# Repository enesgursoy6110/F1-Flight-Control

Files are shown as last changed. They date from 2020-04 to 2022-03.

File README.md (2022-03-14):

It can be used on all flight platforms. Control and telemetry design with Low Power communication module.

RFM69HCW ISM TRANSCEIVER MODULE  :
https://cdn.sparkfun.com/datasheets/Wireless/General/RFM69HCW-V1.1.pdf

FGPMMOPA6H GPS MODULE: 
https://cdn-shop.adafruit.com/datasheets/GlobalTop-FGPMMOPA6H-Datasheet-V0A.pdf

MPL3115A2 Altitude/Pressure Sensor: 
https://cdn.sparkfun.com/datasheets/Sensors/Pressure/MPL3115A2.pdf

MPU6050 Axis Acceleration and Gyro: 
https://invensense.tdk.com/wp-content/uploads/2015/02/MPU-6000-Datasheet1.pdf

HMC6343 3-AXIS DIGITAL COMPASS SOLUTION : 
https://cdn.sparkfun.com/datasheets/Sensors/Magneto/HMC6343.pdf

STM32F103C8T6: 
https://www.st.com/resource/en/datasheet/stm32f103c8.pdf
 
Resources that I have used : https://www.adafruit.com/ , https://www.sparkfun.com/ , https://www.snapeda.com/home/ , https://componentsearchengine.com/

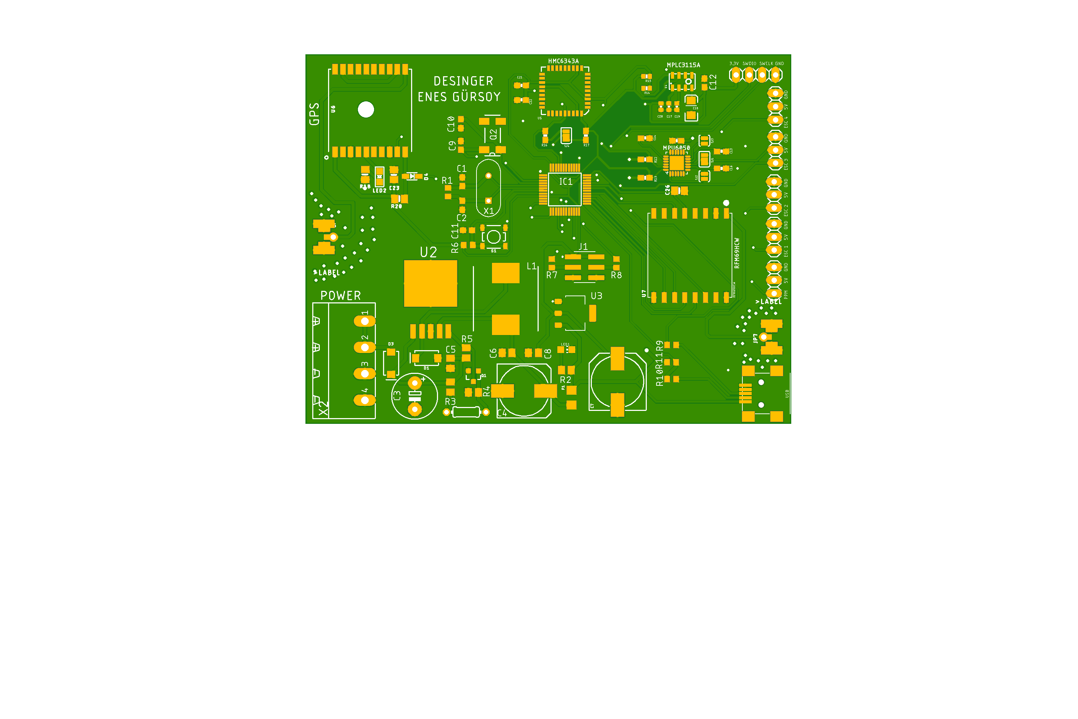
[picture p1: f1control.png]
Banner

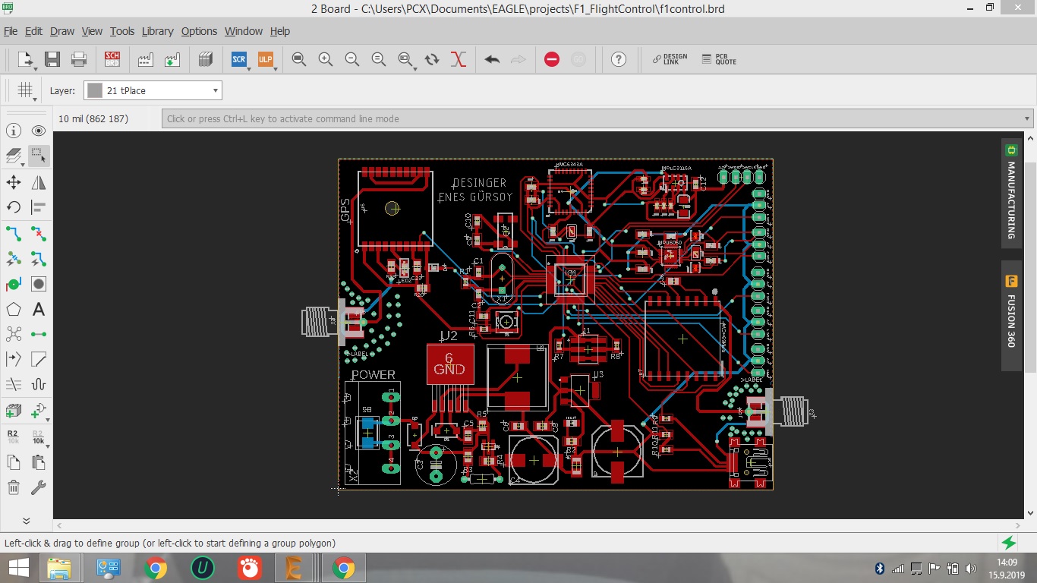
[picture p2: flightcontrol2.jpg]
Banner2

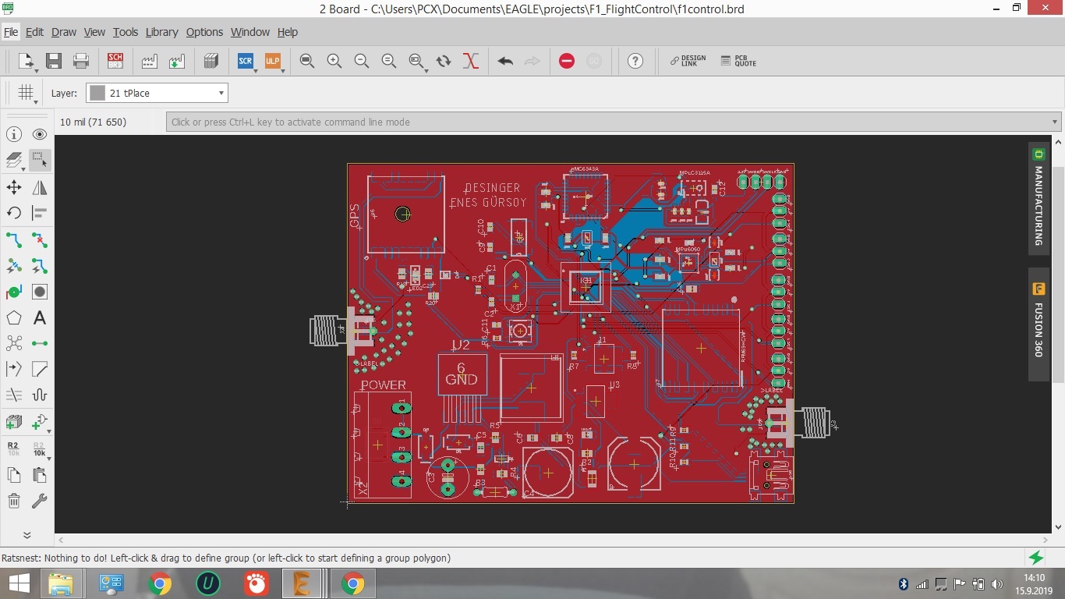
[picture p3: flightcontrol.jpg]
Banner1


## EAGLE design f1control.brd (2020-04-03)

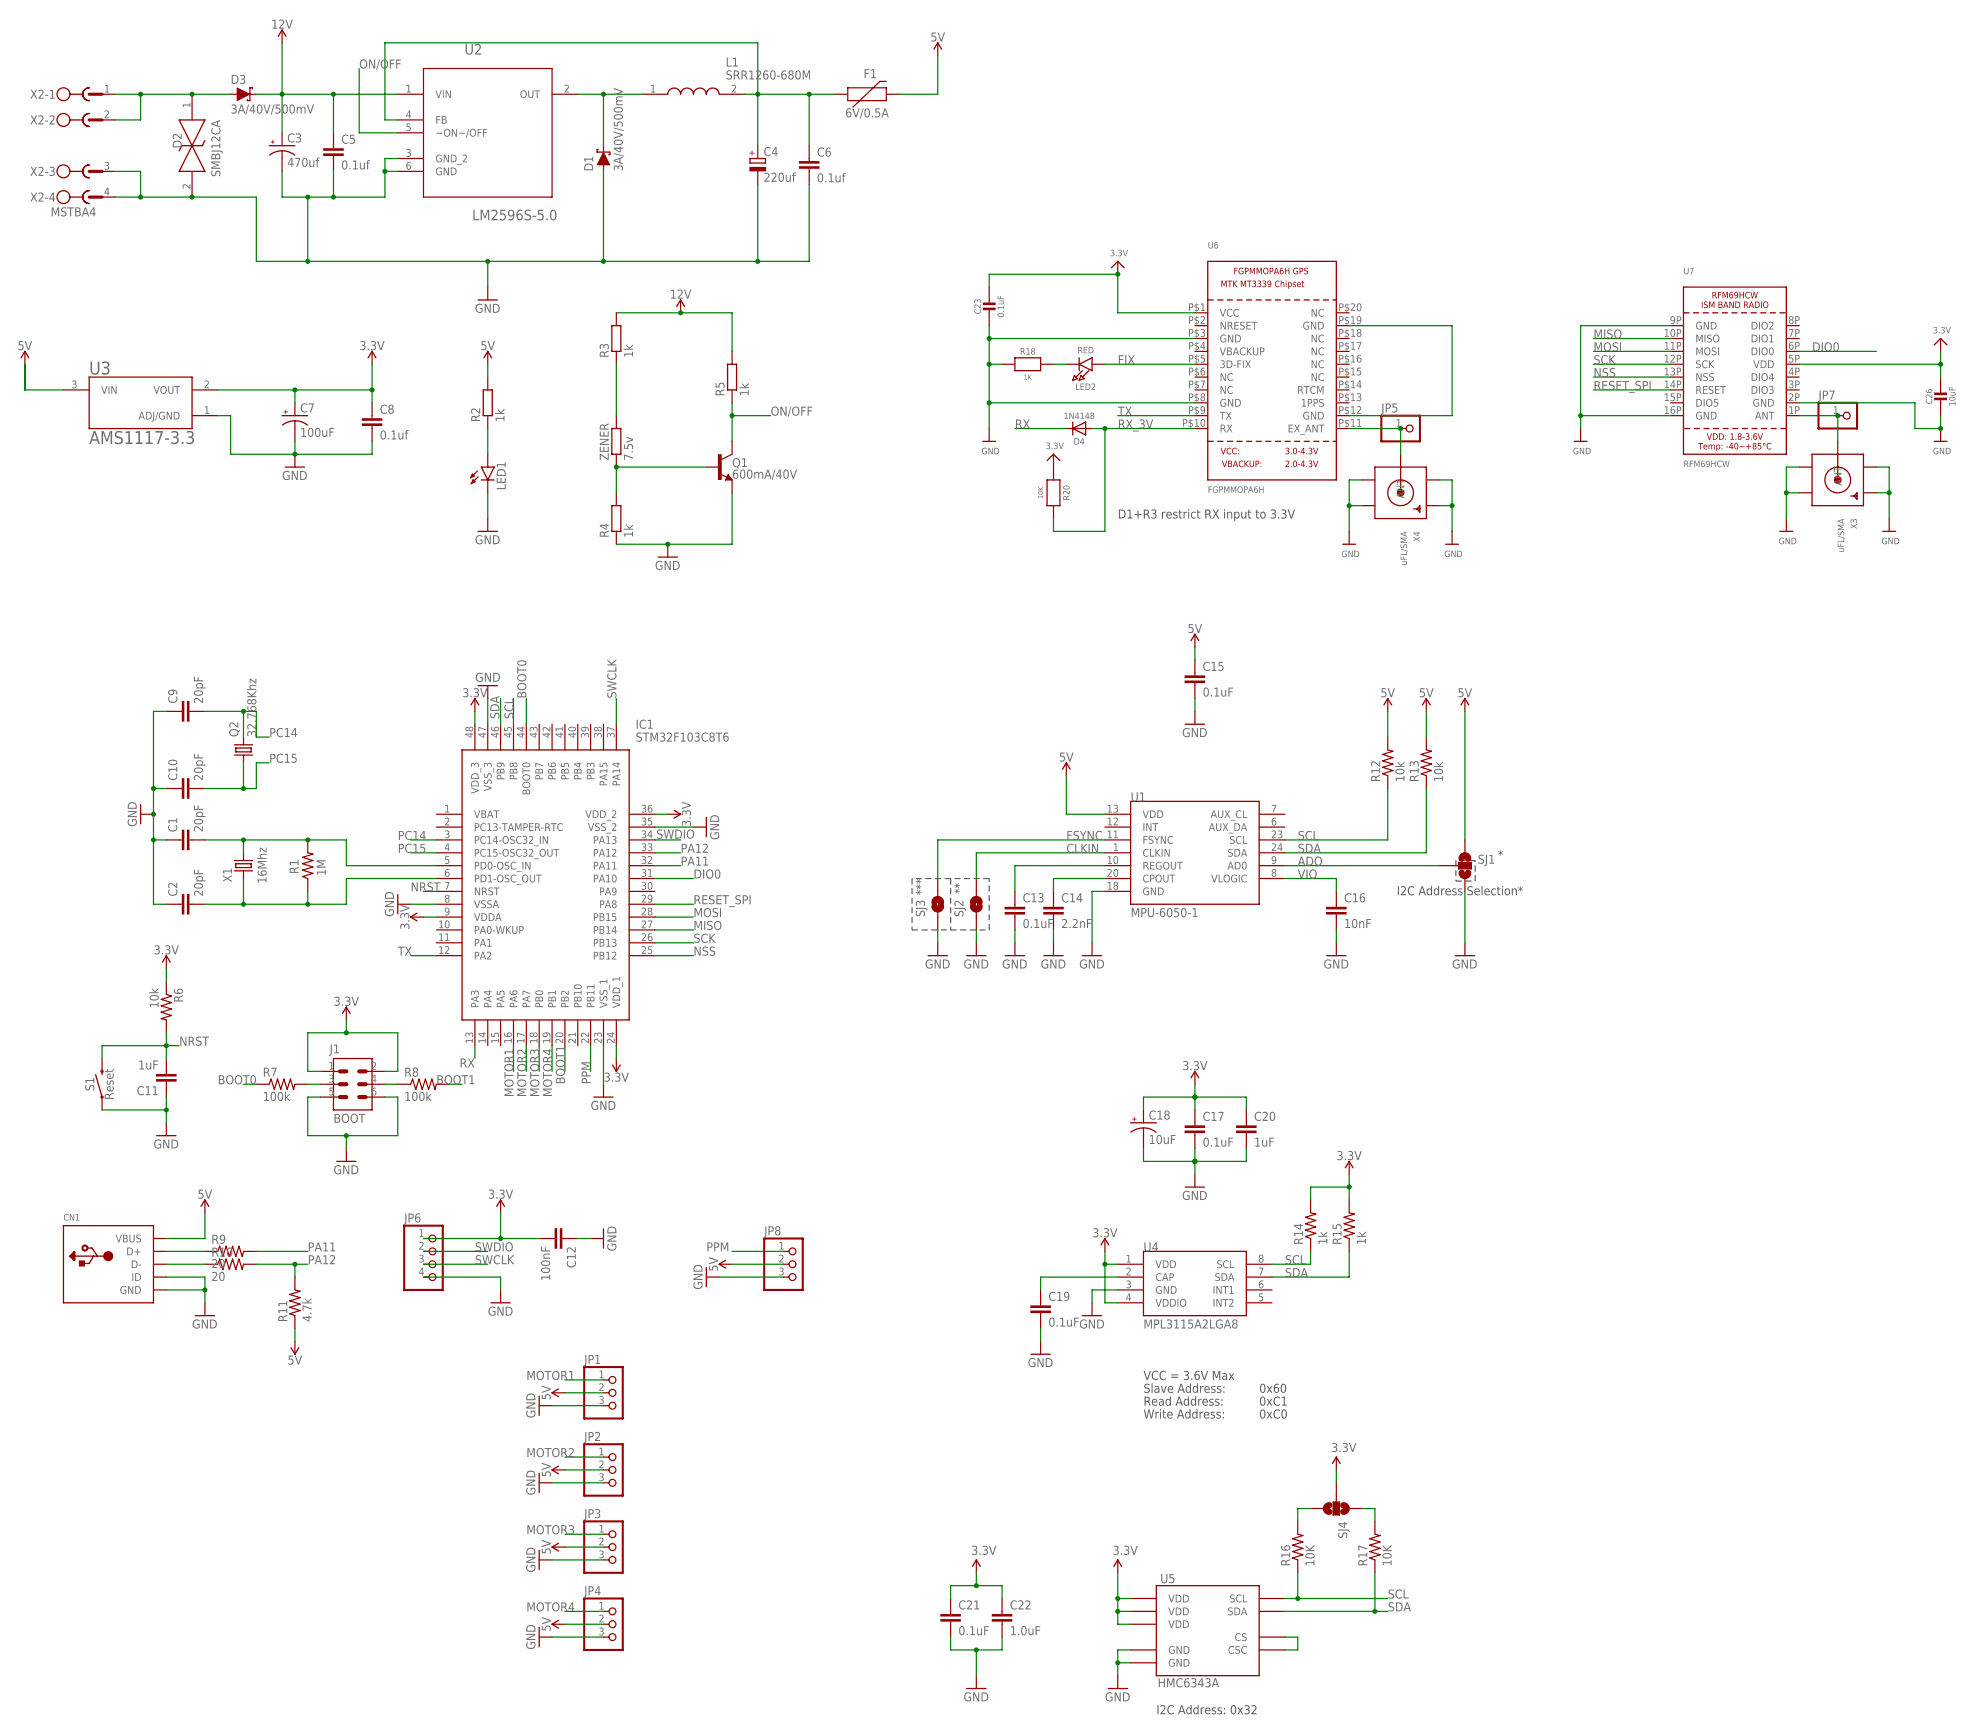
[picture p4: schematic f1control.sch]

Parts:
C1, C2, C9, C10: 20pF; C0603
C3: 470uf; E5-8,5
C4: 220uf; 153CLV-1014
C5, C6, C8: 0.1uf; C0805
C7: 100uF; NIC_10X10.5_CAP
C11: 1uF; C0603
C12: 100nF; C0603
C13, C15, C21: 0.1uF; 0603-CAP
C14: 2.2nF; 0603-CAP
C16: 10nF; 0603-CAP
C17, C19: 0.1uF; 0402-CAP
C18: 10uF; EIA3216
C20: 1uF; 0402-CAP
C22: 1.0uF; 0603-CAP
C23: 0.1uF; 0805-NO
C26: 10uF; 0805-NO
CN1: USBMINIB; USB-MINIB
D1, D3: 3A/40V/500mV; SMA-DIODE
D2: SMBJ12CA; DIONM5443X244N
D4: 1N4148; SOD-323
F1: 6V/0.5A; 1206
IC1: STM32F103C8T6; QFP50P900X900X160-48N
J1: BOOT; 621006245821
JP1, JP2, JP3, JP4, JP8: PINHD-1X3; 1X03
JP5, JP7: HEADER-1X1ROUND; 1X01_ROUND
JP6: PINHD-1X4; 1X04
L1: SRR1260-680M; INDPM125125X650N
LED1: LEDCHIP-LED0805; CHIP-LED0805
LED2: RED; CHIPLED_0805
Q1: 600mA/40V; SOT23-3
Q2: 32.768Khz; MC-306
R1: 1M; R0603
R2, R3, R4, R5: 1k; R0805
R6: 10k; R0603
R7, R8: 100k; R0603
R9, R10: 20; R0603
R11: 4.7k; R0603
R12, R13: 10k; 0603-RES
R14, R15: 1k; 0402-RES
R16, R17: 10K; 0603-RES
R18: 1K; 0805-NO
R20: 10K; 0805-NO
S1: Reset; TACTILE_SWITCH_SMD_4.5MM
SJ1: SOLDERJUMPER_2WAYPASTE2&3; SJ_3_PASTE2&3
SJ2, SJ3: SOLDERJUMPERTRACE; SJ_2S-TRACE
SJ4: SOLDERJUMPER_2WAYPASTE1&2&3; SJ_3_PASTE1&2&3
U1: MPU-6050-1; QFN-24-4MM2
U2: LM2596S-5.0; TO170P1435X465-6N
U3: AMS1117-3.3; SOT229P700X180-4N
U4: MPL3115A2LGA8; LGA8
U5: HMC6343A; LCC36
U6: FGPMMOPA6H
U7: RFM69HCW; RFMHCW_SMT
X1: 16Mhz; XTAL_HC49
X2: MSTBA4
X3, X4: uFL/SMA; SMA_EDGELAUNCH_UFL
ZENER: 7.5v; 0204/7

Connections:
3.3V: C7.+, C8.1, C12.2, C17.1, C18.A (+), C20.1, C21.1, C22.1, C23.1, C26.1, IC1.9 (VDDA), IC1.24 (VDD_1), IC1.36 (VDD_2), IC1.48 (VDD_3), J1.1, J1.2, JP6.1, R6.1, R14.2, R15.2, R20.1, SJ4.2, U3.2 (VOUT), U4.1 (VDD), U4.4 (VDDIO), U5.3 (VDD), U5.11 (VDD), U5.21 (VDD), U6.P$1 (VCC), U7.5P (VDD)
5V: C15.1, CN1.VBUS, F1.2, JP1.2, JP2.2, JP3.2, JP4.2, JP8.2, R2.2, R11.1, R12.2, R13.2, SJ1.1, U1.13 (VDD), U3.3 (VIN)
12V: C3.+, C5.1, D3.C, R3.2, R5.2, U2.1 (VIN)
ADO: SJ1.2, U1.9 (AD0)
BOOT0: IC1.44 (BOOT0), R7.1
BOOT1: IC1.20 (PB2), R8.2
CLKIN: SJ2.2, U1.1 (CLKIN)
DIO0: IC1.31 (PA10), U7.6P (DIO0)
FIX: LED2.A, U6.P$5 (3D-FIX)
FSYNC: SJ3.2, U1.11 (FSYNC)
GND: C1.1, C2.1, C3.-, C4.-, C5.2, C6.2, C7.-, C8.2, C9.1, C10.1, C11.1, C12.1, C13.2, C14.2, C15.2, C16.2, C17.2, C18.C (-), C19.2, C20.2, C21.2, C22.2, C23.2, C26.2, CN1.GND, CN1.ID, D1.A, D2.2, IC1.8 (VSSA), IC1.23 (VSS_1), IC1.35 (VSS_2), IC1.47 (VSS_3), J1.5, J1.6, JP1.3, JP2.3, JP3.3, JP4.3, JP6.4, JP8.3, LED1.C, Q1.2 (E), R4.1, R18.1, S1.2 (1), S1.3 (1), SJ1.3, SJ2.1, SJ3.1, U1.18 (GND), U2.3 (GND_2), U2.6 (GND), U3.1 (ADJ/GND), U4.3 (GND), U5.25 (GND), U5.29 (GND), U6.P$3 (GND), U6.P$8 (GND), U7.2P (GND), U7.9P (GND), U7.16P (GND), X2.3, X2.4, X3.GND@1 (GND1), X3.GND@2 (GND2), X3.GND@3 (GND3), X3.GND@4 (GND4), X4.GND@1 (GND1), X4.GND@2 (GND2), X4.GND@3 (GND3), X4.GND@4 (GND4)
MISO: IC1.27 (PB14), U7.10P (MISO)
MOSI: IC1.28 (PB15), U7.11P (MOSI)
MOTOR1: IC1.16 (PA6), JP1.1
MOTOR2: IC1.17 (PA7), JP2.1
MOTOR3: IC1.18 (PB0), JP3.1
MOTOR4: IC1.19 (PB1), JP4.1
unnamed: J1.3, R7.2
unnamed: C1.2, IC1.5 (PD0-OSC_IN), R1.2, X1.2
unnamed: C2.2, IC1.6 (PD1-OSC_OUT), R1.1, X1.1
unnamed: D1.C, L1.1, U2.2 (OUT)
unnamed: LED1.A, R2.1
unnamed: Q1.1 (B), R4.2, ZENER.1
unnamed: C4.+, C6.1, F1.1, L1.2, U2.4 (FB)
unnamed: R3.1, ZENER.2
unnamed: D2.1, D3.A, X2.1, X2.2
unnamed: J1.4, R8.1
unnamed: C14.1, U1.20 (CPOUT)
unnamed: CN1.D+, R9.1
unnamed: CN1.D-, R10.1
unnamed: C13.1, U1.10 (REGOUT)
unnamed: C19.1, U4.2 (CAP)
unnamed: U5.22 (CS), U5.35 (CSC)
unnamed: R16.2, SJ4.3
unnamed: R17.2, SJ4.1
unnamed: LED2.C, R18.2
unnamed: JP5.1, U6.P$11 (EX_ANT), X4.P (ANT)
unnamed: JP7.1, U7.1P (ANT), X3.P (ANT)
unnamed: U6.P$12 (GND), U6.P$19 (GND)
NRST: C11.2, IC1.7 (NRST), R6.2, S1.1 (2), S1.4 (2)
NSS: IC1.25 (PB12), U7.13P (NSS)
ON/OFF: Q1.3 (C), R5.1, U2.5 (~ON~/OFF)
PA11: IC1.32 (PA11), R9.2
PA12: IC1.33 (PA12), R10.2, R11.2
PC14: C9.2, IC1.3 (PC14-OSC32_IN), Q2.4 (2)
PC15: C10.2, IC1.4 (PC15-OSC32_OUT), Q2.1
PPM: IC1.22 (PB11), JP8.1
RESET_SPI: IC1.29 (PA8), U7.14P (RESET)
RX: D4.C, IC1.13 (PA3)
RX_3V: D4.A, R20.2, U6.P$10 (RX)
SCK: IC1.26 (PB13), U7.12P (SCK)
SCL: IC1.45 (PB8), R12.1, R14.1, R16.1, U1.23 (SCL), U4.8 (SCL), U5.32 (SCL)
SDA: IC1.46 (PB9), R13.1, R15.1, R17.1, U1.24 (SDA), U4.7 (SDA), U5.36 (SDA)
SWCLK: IC1.37 (PA14), JP6.3
SWDIO: IC1.34 (PA13), JP6.2
TX: IC1.12 (PA2), U6.P$9 (TX)
VIO: C16.1, U1.8 (VLOGIC)

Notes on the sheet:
I2C Address Selection*
***
VCC = 3.6V Max
Read Address:
Write Address:
Slave Address:
0x60
0xC1
0xC0
I2C Address: 0x32
D1+R3 restrict RX input to 3.3V

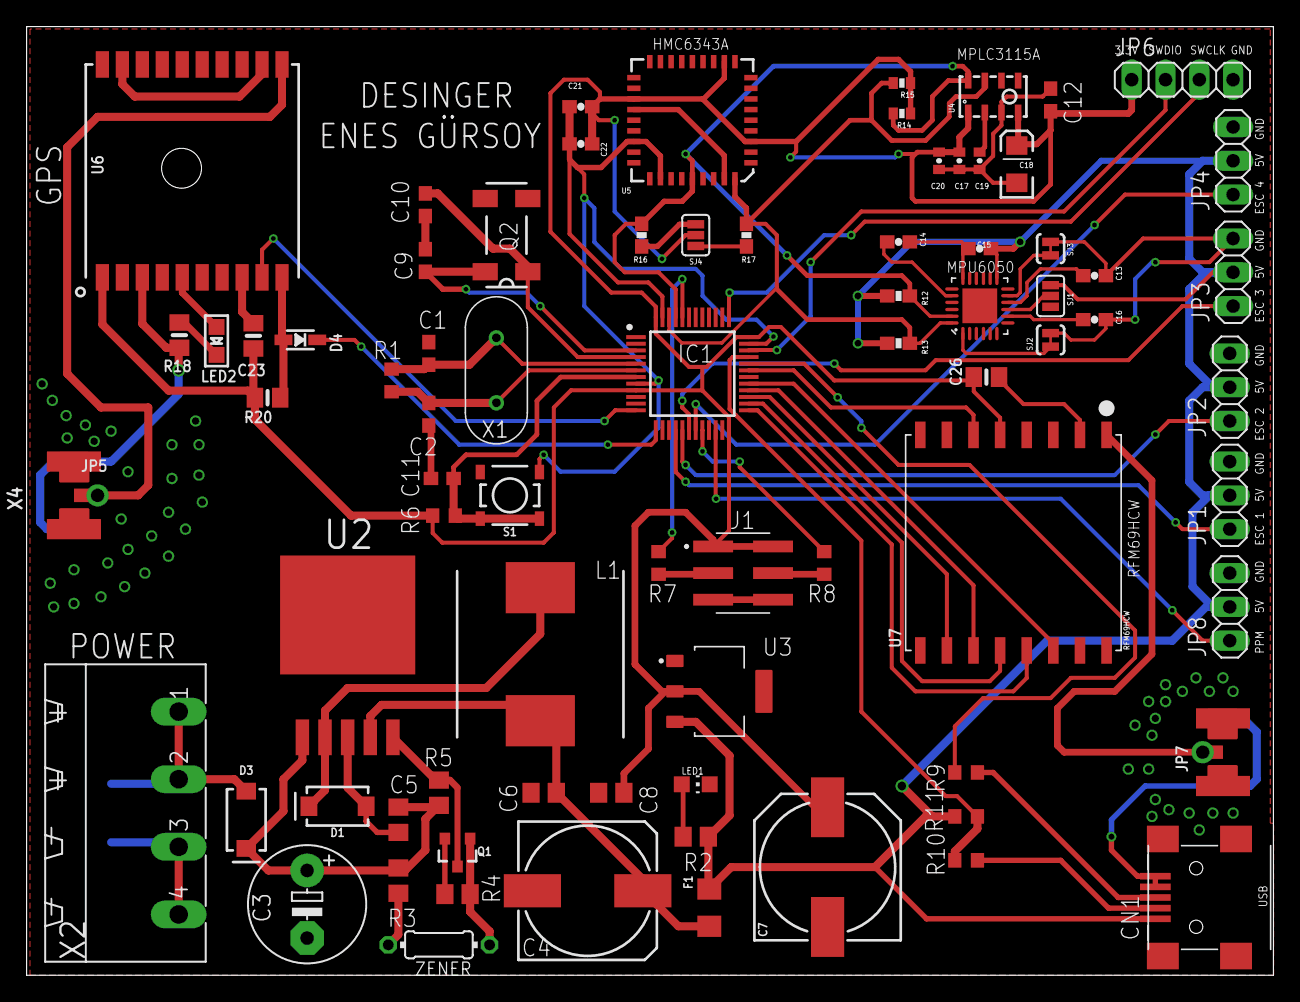
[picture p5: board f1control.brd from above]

Board: 2 copper layers, 93.7 x 71.3 mm, 81 parts (1 on the bottom side), 57 nets.

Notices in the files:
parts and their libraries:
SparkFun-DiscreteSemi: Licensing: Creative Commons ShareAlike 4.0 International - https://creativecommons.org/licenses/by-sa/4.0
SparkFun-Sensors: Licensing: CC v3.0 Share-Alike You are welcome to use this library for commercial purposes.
